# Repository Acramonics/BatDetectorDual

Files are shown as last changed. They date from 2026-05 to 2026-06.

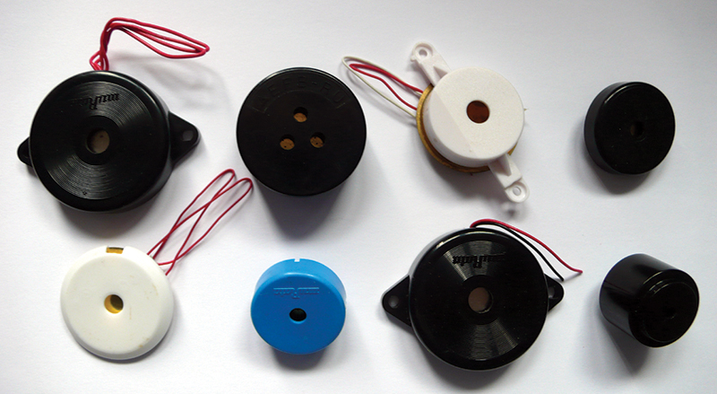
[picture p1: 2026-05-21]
original/NutsAndVolts/NV_0611_Berber_MicLineup.jpg

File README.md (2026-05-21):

Dual Bat Detector
=================

Andrew Martin, acramonics, 2026
-------------------------------

This design combines two circuits for bat detection that use different
principles.

### Frequency Divider

The top part of the circuit diagram and PCB uses two LM386 audio
amplifiers to boost the signal and a 4024 chip to divide the frequency
down to the audio range. This circuit is the 'Enhanced Bat Detector'
from https://batdetector.freevar.com/ This design doesn't require any
tuning of the detector and will cover all frequencies.

### Heterodyne

This bottom part of the circuit diagram and PCB implements a
heterodyne design with the same principle as an AM radio. The circuit
comes from *Nuts and Volts* magazine at
https://www.nutsvolts.com/magazine/article/june2011_berber This uses
just one IC (an LM324 quad opamp). The first opamp is a high-gain
amplifier combined with a high-pass filter (>20kHz); the second opamp
provides further amplification and filtering; the third opamp is an
oscillator with a frequency range of around 15-110kHz; the fourth
opamp is the heterodyne mixer taking the amplified/filtered signal
together with the oscillator signal and outputs the difference between
them.

Building the circuit
--------------------

You can, of course just build one part of the circuit, but the design
is such that you can use a 3PDT switch to select between the two
circuits. (You could also use a 3P3T switch to have an off position
where nothing is connected.)

### Switches

- An ON-OFF-ON toggle switch, the MTS-303R is available from
  [AliExpress](https://www.aliexpress.com/item/1005007484491572.html)
- A 3PDT toggle switch, the TE Connectivity 2-1825139-3, is available
  from
  [Rapid Electronics](https://www.rapidonline.com/te-connectivity-2-1825139-3-toggle-switch-3pdt-on-off-on-pcb-mount-15-1926)
- Alpha produce 4P3T rotary switches such as the SR2611-0403-38F5
  available from
  [Rapid Electronics](https://www.rapidonline.com/taiwan-alpha-sr2611-0403-38f5-make-before-break-rotary-switch-4-pole-3-way-79-0115)
  or the SR2511F-0303-19R0B-E9-S-W-159 available from
  [Mouser](https://www.mouser.co.uk/ProductDetail/Alpha-Taiwan/SR2511F-0303-19R0B-E9-S-W-159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)
- Other choices include 4P3T switches from Alps Alpine
  [RS, SRRM433700](https://uk.rs-online.com/web/p/rotary-switches/1239626)
  and various choices from Lorlin CK  
  [See the datasheet](https://docs.rs-online.com/7602/A700000008016972.pdf)
- A 4P3T rotary switch, the RS26, is also available from AliExpress
  https://www.aliexpress.com/item/1005008776212710.html
- Various 3P3T wafer-style switches are also available and described
  as 'Rotary Band Switches' See:
  - https://www.aliexpress.com/item/1005011839909128.html
  - https://www.aliexpress.com/item/1005007021912980.html
  - https://www.aliexpress.com/item/1005005723913772.html
  - https://www.aliexpress.com/item/1005011597813751.html
  - https://www.aliexpress.com/item/1005006184759913.html
  - https://www.aliexpress.com/item/1005010336131768.html
  - https://www.aliexpress.com/item/1005008856647634.html

### Potentiometer

The dual-gang B100K potentiometer is a compromise between the
recommended B50K for the heterodyne circuit and the A220K for the
frequency divider. It should be fine for the latter, but it may be
necessary to put a 47K resistor in parallel with the pot used for the
heterodyne circuit.

### Optional parts

R2, R3, C5 and C10 in the frequency divider circuit shouldn't be
needed but can be added if there is instability in the
amplifier.  Similarly, C3 and C8 shouldn't be needed.

L1 and L2 may not be needed depending on the transducer/microphone used.

### Transducer/Microphone

40kHz ultrasonic transducer are easily available from AliExpress and
most good component suppliers. However, according to the *Nuts and
Volts* article, a simple piezo or ceramic sounder used as a microphone
can be better. produce superior results. For these, L1 and L2 are not
needed. 

### Headphones/earpiece

A crystal earpiece is ideal.

### Component values

Some of the values are dependent on the sensor/microphone used.

**With a 40kHz ultrasonic transducer:**

- L1=6.8mH
- R1=150R or 220R
- RV1 should be set to a value in the range 150R to 2K2. 470R to 1K5
  is a good starting point. Increased values can be used if the
  detector is too noisy or oscillates.
- L2 is in the range 10uH to 6.8mH

**With other piezo/ceramic transducers**

- L1/L2 are not used
- R1 and RV1 adjusted as above

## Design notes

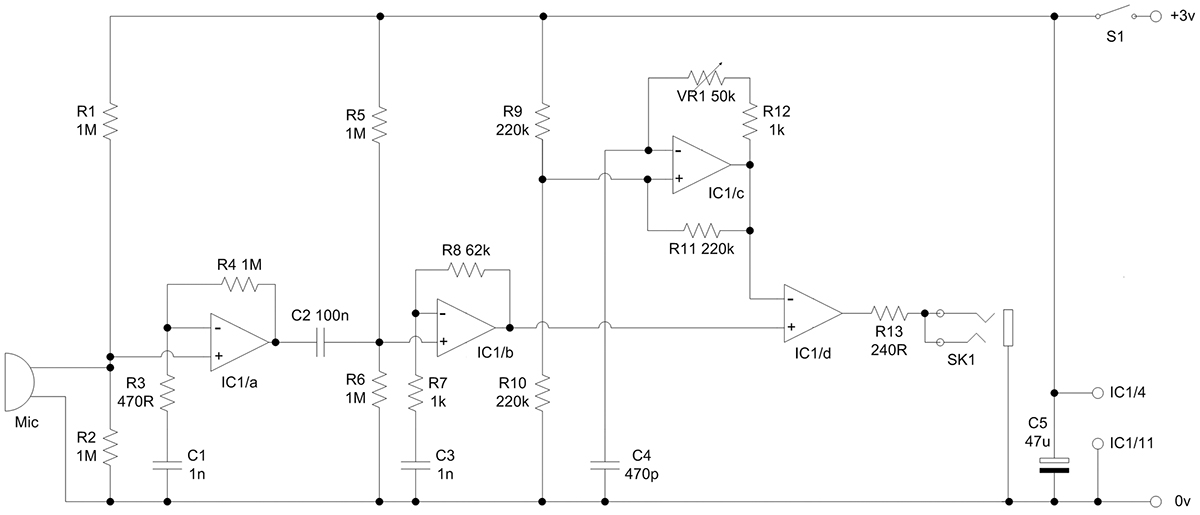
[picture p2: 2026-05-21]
original/NutsAndVolts/NV_0611_Berber_BatDetSchematic.jpg

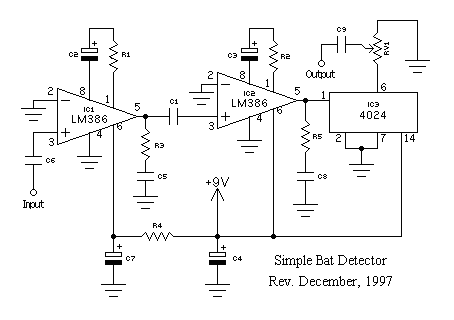
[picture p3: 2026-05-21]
original/FreeVar/SBD2Sch.gif

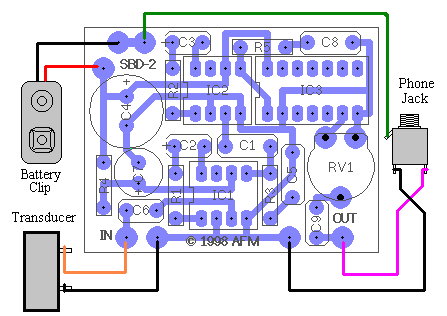
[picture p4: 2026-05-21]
original/FreeVar/SBD2PCB.gif

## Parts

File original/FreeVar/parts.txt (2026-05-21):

https://batdetector.freevar.com/

Circuit Designator	Component Value	Purpose of Component
R1, R2	Varies with transducer used	Sets gains of amplifier stages
R3, R5	N/A	Amplifier stability components ( not used at this time )
R4	220 ohms	Power supply isolation for first amplifier stage
RV1	10K ohms	Volume setting potentiometer
C1	.047 uf	Signal coupling between amplifier stages
C2, C3	10 uf	Amplifier gain control components
C4	470 uf	Main power supply filter
C5, C8	N/A	Amplifier stability components ( not used at this time )
C6	.022 uf	Couples transducer signal to input of first amplifier stage
C7	220 uf	First amplifier power supply filter
C9	.022 uf	Couples detector output to earphone
IC1,IC2 LM386
IC3     4024

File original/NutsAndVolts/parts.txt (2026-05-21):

https://www.nutsvolts.com/magazine/article/june2011_berber

Resistors	All 250 mW 5% axial carbon film. 
R1	1M
R2	1M
R3	470R
R4	1M
R5	1M
R6	1M
R7	1K
R8	62K
R9	220K
R10	220K
R11	220K
R12	1K
R13	240R
VR3	50K rotary potentiometer (see text)

Capacitors	All polyester or ceramic except C5.
C1	1 n 
C2	100 n
C3	1 n
C4	470 p
C5	47 µF 10V electrolytic 

Active Components
IC1	LM324 quad audio op-amp or similar (see text)

Miscellaneous
Mic	Piezo type (see text)
SK1	3.5 mm stereo phone socket
S1	SPST switch (see text)
Battery	Two-off AA cells for 3V operation
Battery Box	Double AA box to suit construction
Project Case	Select according to construction needs
Headphones	Dynamic in-ear or on-ear type, 300R approx.

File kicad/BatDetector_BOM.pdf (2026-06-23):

BatDetector

Page 1

Reference | Qty Value | Footprint
C1,C11 | 2 22nF | Capacitor_THT:C_Rect_L7.0mm_W2.5mm_P5.00mm
C2,C7 | 2 10uF | Capacitor_THT:CP_Radial_D5.0mm_P2.00mm
C3,C8 | 2 *10uF | Capacitor_THT:CP_Radial_D5.0mm_P2.00mm
C4 | 1 220uF | Capacitor_THT:CP_Radial_D8.0mm_P3.50mm
C5,C10 | 2 *Inf | Capacitor_THT:C_Rect_L7.0mm_W2.5mm_P5.00mm
C6 | 1 47nF | Capacitor_THT:C_Rect_L7.0mm_W2.5mm_P5.00mm
C9 | 1 470uF | Capacitor_THT:CP_Radial_D10.0mm_P5.00mm
C12,C14 | 2 1nF | Capacitor_THT:C_Rect_L7.0mm_W2.5mm_P5.00mm
C13 | 1 100nF | Capacitor_THT:C_Rect_L7.0mm_W2.5mm_P5.00mm
C15 | 1 470pF | Capacitor_THT:C_Rect_L7.0mm_W2.5mm_P5.00mm
C16 | 1 47uF | Capacitor_THT:CP_Radial_D6.3mm_P2.50mm
J1,J2,J3,J4 | 4 Conn_01x03_Pin | Connector_Molex:Molex_KK-254_AE-6410-03A_1x03_P2.54mm_Vertical
J5,J6 | 2 Conn_01x02_Pin | Connector_Molex:Molex_KK-254_AE-6410-02A_1x02_P2.54mm_Vertical
J7,J8,J9 | 3 Conn_01x02_Pin | Connector_Molex:Molex_KK-254_AE-6410-02A_1x02_P2.54mm_Vertical
JP1 | 1 Conn_02x03_Odd_Even Connector_PinHeader_2.54mm:PinHeader_2x03_P2.54mm_Vertical
L1 | 1 +6.8mH | Inductor_THT:L_Axial_L5.3mm_D2.2mm_P10.16mm_Horizontal_Vishay_IM-1
L2 | 1 *10uH | Inductor_THT:L_Axial_L5.3mm_D2.2mm_P10.16mm_Horizontal_Vishay_IM-1
R1 | 1 +150R | Resistor_THT:R_Axial_DIN0207_L6.3mm_D2.5mm_P10.16mm_Horizontal
R2,R3 | 2 *Inf | Resistor_THT:R_Axial_DIN0207_L6.3mm_D2.5mm_P10.16mm_Horizontal
R4 | 1 220R | Resistor_THT:R_Axial_DIN0207_L6.3mm_D2.5mm_P10.16mm_Horizontal
R5,R6,R8,R9,R10 | 5 1M | Resistor_THT:R_Axial_DIN0207_L6.3mm_D2.5mm_P10.16mm_Horizontal
R7 | 1 470R | Resistor_THT:R_Axial_DIN0207_L6.3mm_D2.5mm_P10.16mm_Horizontal
R11 | 1 1K | Resistor_THT:R_Axial_DIN0207_L6.3mm_D2.5mm_P10.16mm_Horizontal
R12,R13,R14 | 3 220k | Resistor_THT:R_Axial_DIN0207_L6.3mm_D2.5mm_P10.16mm_Horizontal
R15 | 1 1k | Resistor_THT:R_Axial_DIN0207_L6.3mm_D2.5mm_P10.16mm_Horizontal
R16 | 1 240R | Resistor_THT:R_Axial_DIN0207_L6.3mm_D2.5mm_P10.16mm_Horizontal
RV1 | 1 B5K | Potentiometer_THT:Potentiometer_Vishay_T73YP_Vertical
RV2 | 1 B50k
RV4 | 1 B100k dual
SW1 | 1 2P3T toggle/rotary
U1,U2 | 2 LM386 | Package_DIP:DIP-8_W7.62mm
U3 | 1 4024 | Package_DIP:DIP-14_W7.62mm
U4 | 1 LM324 | Package_DIP:DIP-14_W7.62mm

* Shouldn’t be needed unless unstable
+ Depends on transducer

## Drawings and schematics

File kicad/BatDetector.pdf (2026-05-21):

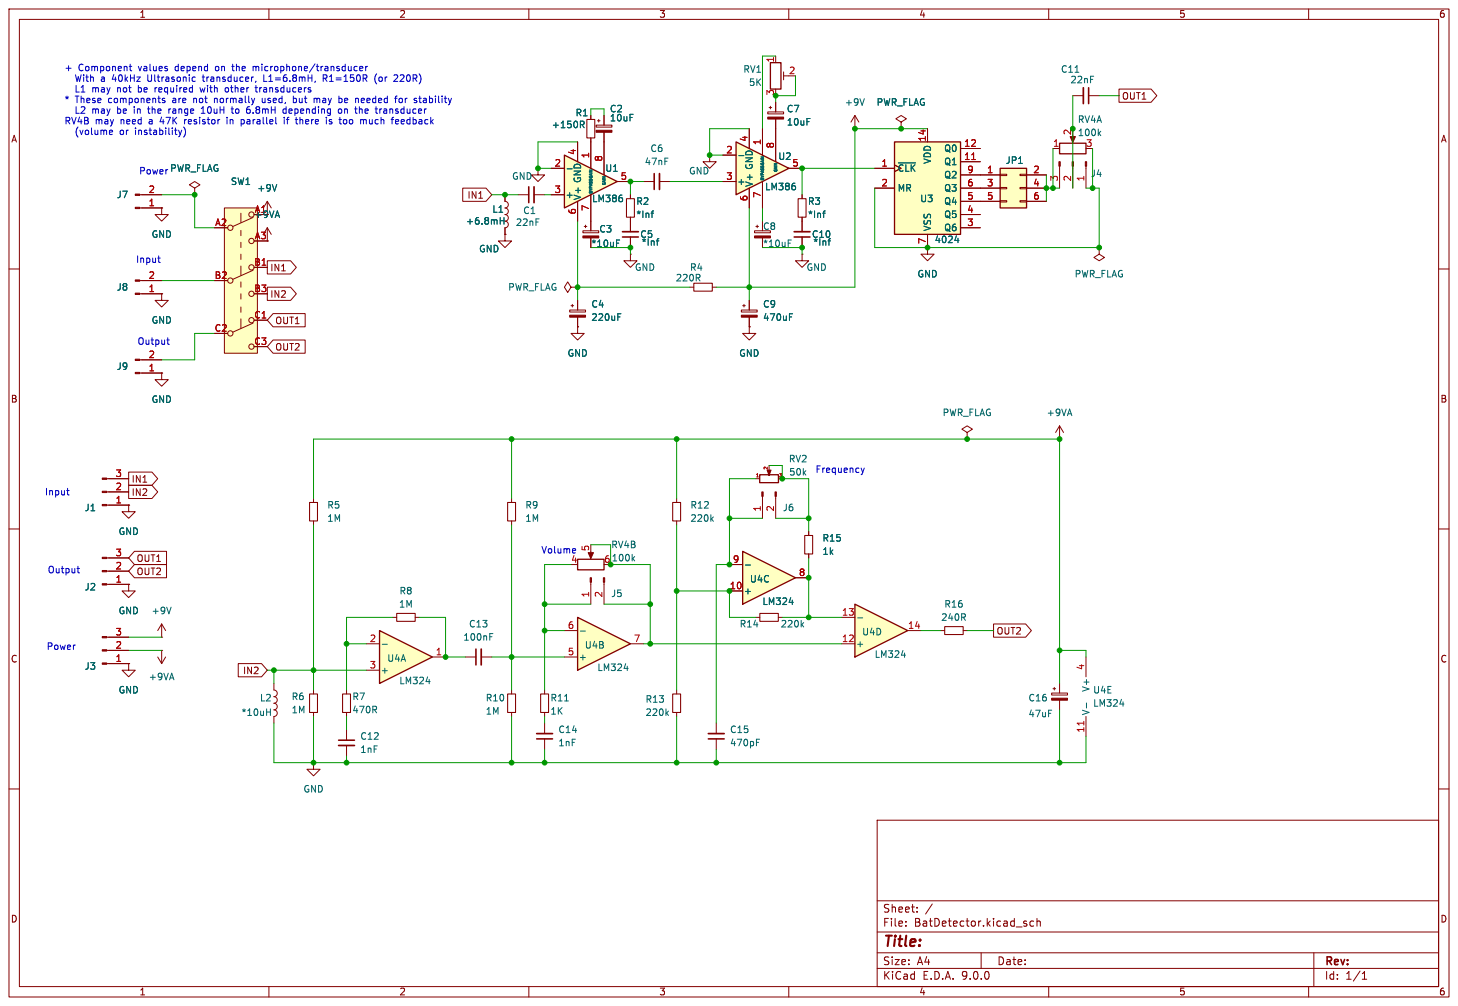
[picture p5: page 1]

Id: 1/1 Title: File: BatDetector.kicad_sch Sheet: / C15

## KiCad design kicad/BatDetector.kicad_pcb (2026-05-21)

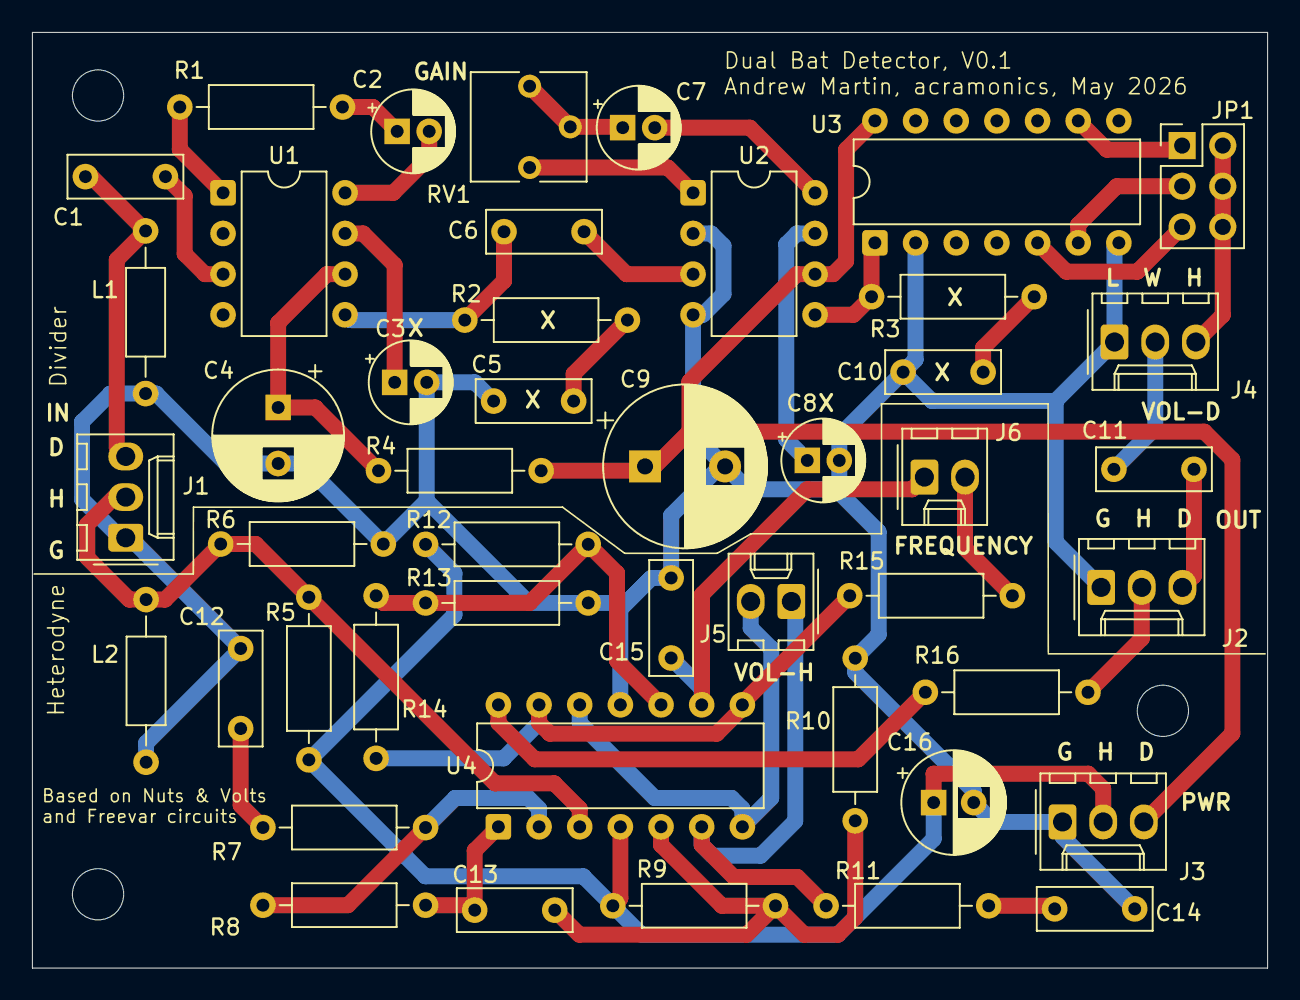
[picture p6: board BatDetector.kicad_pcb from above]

Board: 2 copper layers, 77.2 x 58.5 mm, 46 parts (0 on the bottom side), 39 nets.

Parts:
C1, C11: 22nF; C_Rect_L7.0mm_W2.5mm_P5.00mm
C2, C7: 10uF; CP_Radial_D5.0mm_P2.00mm
C3, C8: *10uF; CP_Radial_D5.0mm_P2.00mm
C4: 220uF; CP_Radial_D8.0mm_P3.50mm
C5, C10: *Inf; C_Rect_L7.0mm_W2.5mm_P5.00mm
C6: 47nF; C_Rect_L7.0mm_W2.5mm_P5.00mm
C9: 470uF; CP_Radial_D10.0mm_P5.00mm
C12, C14: 1nF; C_Rect_L7.0mm_W2.5mm_P5.00mm
C13: 100nF; C_Rect_L7.0mm_W2.5mm_P5.00mm
C15: 470pF; C_Rect_L7.0mm_W2.5mm_P5.00mm
C16: 47uF; CP_Radial_D6.3mm_P2.50mm
J1, J2, J3, J4: Conn_01x03_Pin; Molex_KK-254_AE-6410-03A_1x03_P2.54mm_Vertical
J5, J6: Conn_01x02_Pin; Molex_KK-254_AE-6410-02A_1x02_P2.54mm_Vertical
JP1: Conn_02x03_Odd_Even; PinHeader_2x03_P2.54mm_Vertical
L1: +6.8mH; L_Axial_L5.3mm_D2.2mm_P10.16mm_Horizontal_Vishay_IM-1
L2: *10uH; L_Axial_L5.3mm_D2.2mm_P10.16mm_Horizontal_Vishay_IM-1
R1: +150R; R_Axial_DIN0207_L6.3mm_D2.5mm_P10.16mm_Horizontal
R2, R3: *Inf; R_Axial_DIN0207_L6.3mm_D2.5mm_P10.16mm_Horizontal
R4: 220R; R_Axial_DIN0207_L6.3mm_D2.5mm_P10.16mm_Horizontal
R5, R6, R8, R9, R10: 1M; R_Axial_DIN0207_L6.3mm_D2.5mm_P10.16mm_Horizontal
R7: 470R; R_Axial_DIN0207_L6.3mm_D2.5mm_P10.16mm_Horizontal
R11: 1K; R_Axial_DIN0207_L6.3mm_D2.5mm_P10.16mm_Horizontal
R12, R13, R14: 220k; R_Axial_DIN0207_L6.3mm_D2.5mm_P10.16mm_Horizontal
R15: 1k; R_Axial_DIN0207_L6.3mm_D2.5mm_P10.16mm_Horizontal
R16: 240R; R_Axial_DIN0207_L6.3mm_D2.5mm_P10.16mm_Horizontal
RV1: 5K; Potentiometer_Vishay_T73YP_Vertical
U1, U2: LM386; DIP-8_W7.62mm
U3: 4024; DIP-14_W7.62mm
U4: LM324; DIP-14_W7.62mm

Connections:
+9V: C9.1, J3.3, R4.2, U2.6 (V+), U3.14 (VDD)
+9VA: C16.1, J3.2, R5.1, R9.2, R12.1, U4.4 (V+)
GND: C3.2, C4.2, C5.1, C8.2, C9.2, C10.1, C12.2, C14.1, C15.1, C16.2, J1.1, J2.1, J3.1, J4.1, L1.2, L2.2, R6.2, R10.1, R13.2, U1.2 (-), U1.4 (GND), U2.2 (-), U2.4 (GND), U3.2 (MR), U3.7 (VSS), U4.11 (V-)
IN1: C1.1, J1.3, L1.1
IN2: J1.2, L2.1, R5.2, R6.1, U4.3 (+)
unnamed: C2.1, R1.1
unnamed: C2.2, U1.8 (GAIN)
unnamed: C5.2, R2.2
unnamed: C6.1, R2.1, U1.5
unnamed: C7.1, RV1.2, RV1.3
unnamed: C7.2, U2.8 (GAIN)
unnamed: C10.2, R3.2
unnamed: C12.1, R7.2
unnamed: C13.1, R8.2, U4.1
unnamed: C14.2, R11.1
unnamed: C11.2, J4.2
unnamed: J4.3, JP1.2, JP1.4, JP1.6
unnamed: J5.1, R11.2, U4.6 (-)
unnamed: J5.2, U4.7, U4.12 (+)
unnamed: C15.2, J6.1, U4.9 (-)
unnamed: J6.2, R15.2
unnamed: JP1.1, U3.9 (Q2)
unnamed: JP1.3, U3.6 (Q3)
unnamed: JP1.5, U3.5 (Q4)
unnamed: R1.2, U1.1 (GAIN)
unnamed: R16.2, U4.14
unnamed: RV1.1, U2.1 (GAIN)
unnamed: C1.2, U1.3 (+)
unnamed: C3.1, U1.7 (BYPASS)
unnamed: C4.1, R4.1, U1.6 (V+)
unnamed: C6.2, U2.3 (+)
unnamed: C8.1, U2.7 (BYPASS)
unnamed: R3.1, U2.5, U3.1 (~CLK)
unnamed: R7.1, R8.1, U4.2 (-)
unnamed: C13.2, R9.1, R10.2, U4.5 (+)
unnamed: R12.2, R13.1, R14.1, U4.10 (+)
unnamed: R14.2, R15.1, U4.8, U4.13 (-)
OUT1: C11.1, J2.3
OUT2: J2.2, R16.1

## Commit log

2026-05-21 Some layout tweaks
    [BatDetector.kicad_pcb, BatDetector.kicad_sch]
2026-05-21 Regenerated gerbers
2026-05-26 Added BOM
    [BatDetector_BOM.ods]
2026-06-23 Added BOM pdf
    [BatDetector_BOM.ods]
